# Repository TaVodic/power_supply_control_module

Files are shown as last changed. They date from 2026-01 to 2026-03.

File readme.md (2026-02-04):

# Laboratory Power Supply Control Module (PSCM)   

Module is an upgarde for Nice-Power SPS305 0-30V/0-5A laboratory power supply. Module use encoders instead of potentiometers. Based on ATmega328PB.
Using arduino-cli framework.  
### Features:
* Encoders EC12E, fine and coarse set of volatge and current
* Digital potentiometers MCP4251
* ATmega328PB
* Sniffing the PS voltage, current and power - providing a feedback
* UART connection for PC connection and automated PS setting

### Libraries used:
* Encoder_mt, [original](https://github.com/PaulStoffregen/Encoder) modified to use PCINT and optimized for the use-case
* DispSniff, sniffing SDI & CLK pins of TM1640 (of the original PS) to capture voltage, current and power values of the PS
* MCP4251, [original](https://github.com/kulbhushanchand/MCP4251)

## [Schematic v1.0.0](docu/pscm_schematic_v1.0.0.pdf)

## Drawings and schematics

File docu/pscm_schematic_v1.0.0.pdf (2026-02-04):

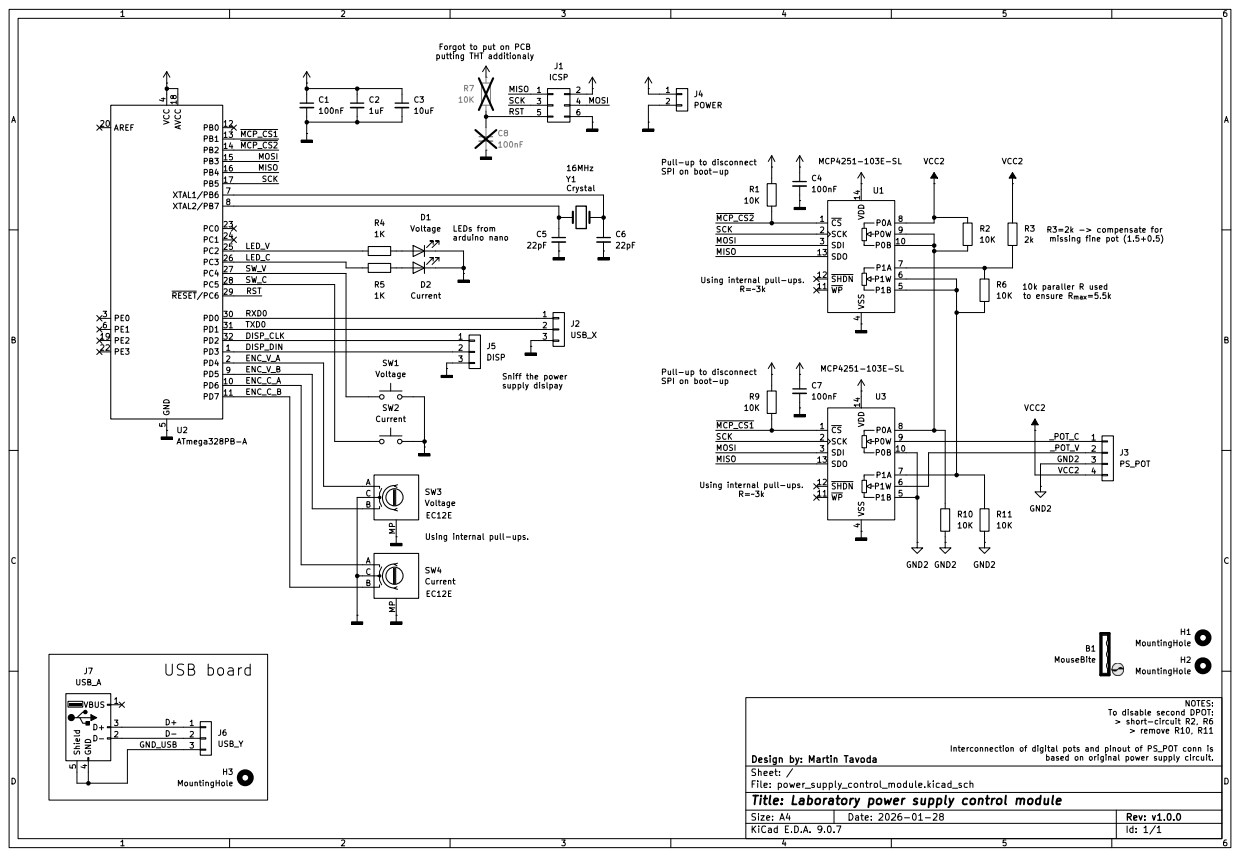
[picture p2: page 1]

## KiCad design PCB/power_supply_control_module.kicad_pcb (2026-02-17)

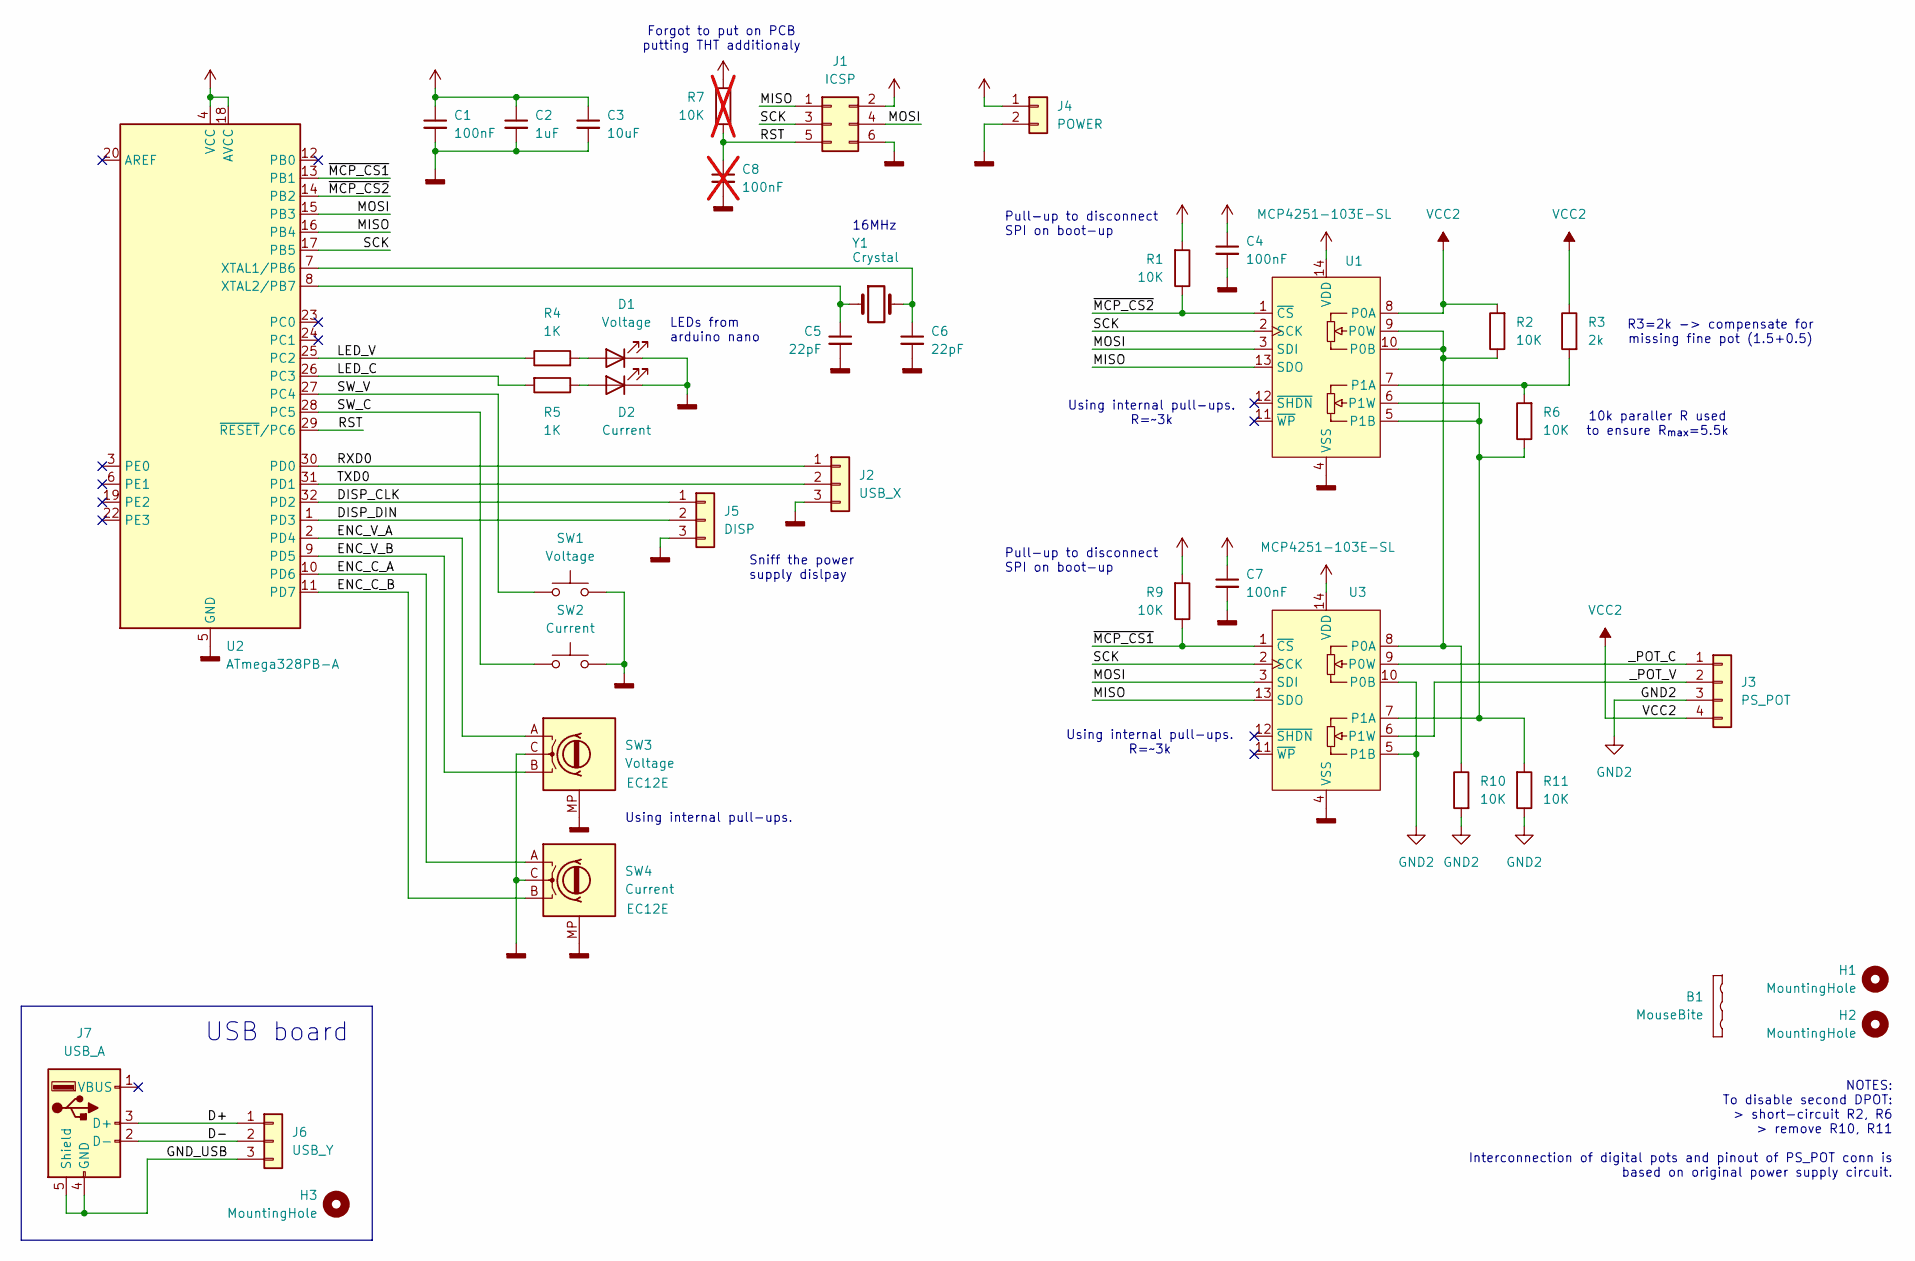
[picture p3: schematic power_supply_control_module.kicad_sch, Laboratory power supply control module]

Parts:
B1: MouseBite; mouse-bite-3mm-slot-jlcpcb
C1, C4, C7: 100nF; C_1206_3216Metric_Pad1.33x1.80mm_HandSolder
C2: 1uF; C_1206_3216Metric_Pad1.33x1.80mm_HandSolder
C3: 10uF; C_1206_3216Metric_Pad1.33x1.80mm_HandSolder
C5, C6: 22pF; C_1206_3216Metric_Pad1.33x1.80mm_HandSolder
C8: 100nF; C_1206_3216Metric_Pad1.33x1.80mm_HandSolder; not fitted
D1: Voltage; LED_0603_1608Metric_Pad1.05x0.95mm_HandSolder
D2: Current; LED_0603_1608Metric_Pad1.05x0.95mm_HandSolder
H1, H2, H3: MountingHole; MountingHole_3.2mm_M3_ISO7380
J1: ICSP; PinHeader_2x03_P2.54mm_Vertical
J2: USB_X; SHDR3W50P0X200_1X3_800X470X640P
J3: PS_POT; JST_XH_B4B-XH-A_1x04_P2.50mm_Vertical
J4: POWER; 140502415001
J5: DISP; SHDR3W50P0X200_1X3_800X470X640P
J6: USB_Y; PinHeader_1x03_P2.00mm_Vertical
J7: USB_A; USB_A_Molex_105057_Vertical
R1, R2, R6, R9, R10, R11: 10K; R_1206_3216Metric_Pad1.30x1.75mm_HandSolder
R3: 2k; R_1206_3216Metric_Pad1.30x1.75mm_HandSolder
R4, R5: 1K; R_1206_3216Metric_Pad1.30x1.75mm_HandSolder
R7: 10K; R_1206_3216Metric_Pad1.30x1.75mm_HandSolder; not fitted
SW1: Voltage; SW_TH_Tactile_Omron_B3F-107x
SW2: Current; SW_TH_Tactile_Omron_B3F-107x
SW3: Voltage; RotaryEncoder_Alps_EC12E_Vertical_H20mm
SW4: Current; RotaryEncoder_Alps_EC12E_Vertical_H20mm
U1, U3: MCP4251-103E-SL; SOIC-14_3.9x8.7mm_P1.27mm
U2: ATmega328PB-A; TQFP-32_7x7mm_P0.8mm
Y1: Crystal; Crystal_HC49-4H_Vertical

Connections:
/D+: J6.1, J7.3 (D+)
/D-: J6.2, J7.2 (D-)
/DISP_CLK: J5.1, U2.32 (PD2)
/DISP_DIN: J5.2, U2.1 (PD3)
/ENC_C_A: SW4.A, U2.10 (PD6)
/ENC_C_B: SW4.B, U2.11 (PD7)
/ENC_V_A: SW3.A, U2.2 (PD4)
/ENC_V_B: SW3.B, U2.9 (PD5)
/GND_USB: J6.3, J7.4 (GND), J7.5 (Shield)
/LED_C: R5.2, U2.26 (PC3)
/LED_V: R4.1, U2.25 (PC2)
/MISO: J1.1, U1.13 (SDO), U2.16 (PB4), U3.13 (SDO)
/MOSI: J1.4, U1.3 (SDI), U2.15 (PB3), U3.3 (SDI)
/RST: C8.1, J1.5, R7.1, U2.29 (~RESET/PC6)
/RXD0: J2.1, U2.30 (PD0)
/SCK: J1.3, U1.2 (SCK), U2.17 (PB5), U3.2 (SCK)
/SW_C: SW2.1, U2.28 (PC5)
/SW_V: SW1.1, U2.27 (PC4)
/TXD0: J2.2, U2.31 (PD1)
/_POT_C: J3.1, U3.9 (P0W)
/_POT_V: J3.2, U3.6 (P1W)
/~MCP_CS1: R9.1, U2.13 (PB1), U3.1 (~CS)
/~MCP_CS2: R1.1, U1.1 (~CS), U2.14 (PB2)
GND2: J3.3, R10.2, R11.1, U3.5 (P1B), U3.10 (P0B)
GNDD: C1.2, C2.2, C3.2, C4.2, C5.2, C6.2, C7.2, C8.2, D1.1 (K), D2.1 (K), J1.6, J2.3, J4.2, J5.3, SW1.2, SW2.2, SW3.C, SW3.MP, SW4.C, SW4.MP, U1.4 (VSS), U2.5 (GND), U2.21 (GND), U3.4 (VSS)
unnamed: D1.2 (A), R4.2
unnamed: D2.2 (A), R5.1
unnamed: R2.1, R10.1, U1.9 (P0W), U1.10 (P0B), U3.8 (P0A)
unnamed: R3.2, R6.2, U1.7 (P1A)
unnamed: R6.1, R11.2, U1.5 (P1B), U1.6 (P1W), U3.7 (P1A)
unnamed: C6.1, U2.7 (XTAL1/PB6), Y1.2
unnamed: C5.1, U2.8 (XTAL2/PB7), Y1.1
VCC: C1.1, C2.1, C3.1, C4.1, C7.1, J1.2, J4.1, R1.2, R7.2, R9.2, U1.14 (VDD), U2.4 (VCC), U2.18 (AVCC), U3.14 (VDD)
VCC2: J3.4, R2.2, R3.1, U1.8 (P0A)

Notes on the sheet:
Forgot to put on PCB putting THT additionaly
Using internal pull-ups. R=~3k
Pull-up to disconnect SPI on boot-up
10k paraller R used to ensure R_{max}=5.5k
NOTES: To disable second DPOT: > short-circuit R2, R6 > remove R10, R11 Interconnection of digital pots and pinout of PS_POT conn is based on original power supply circuit.
Using internal pull-ups.
R3=2k -> compensate for missing fine pot (1.5+0.5)
16MHz
USB board
Sniff the power supply dislpay
LEDs from arduino nano

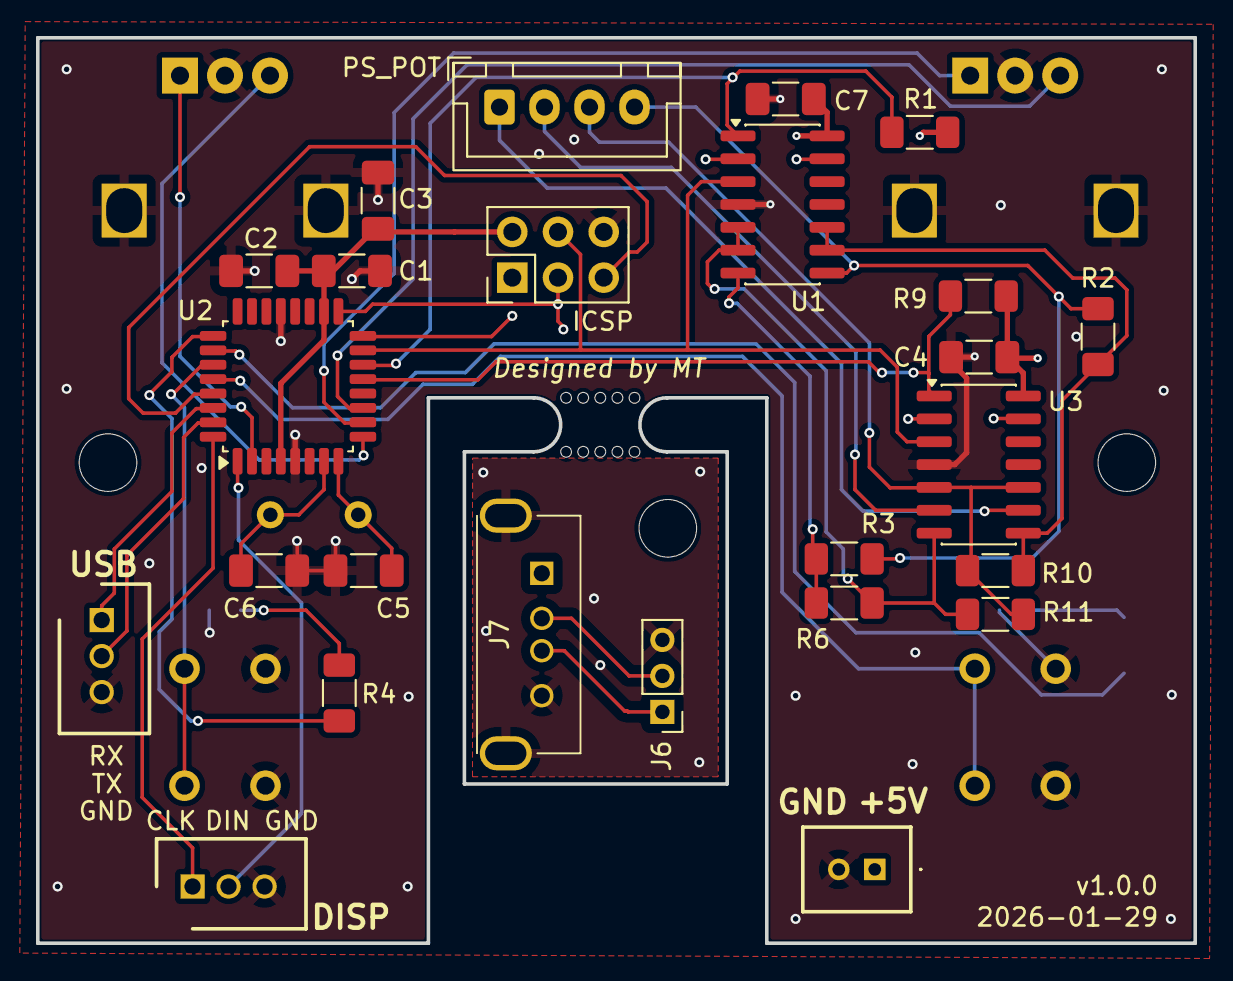
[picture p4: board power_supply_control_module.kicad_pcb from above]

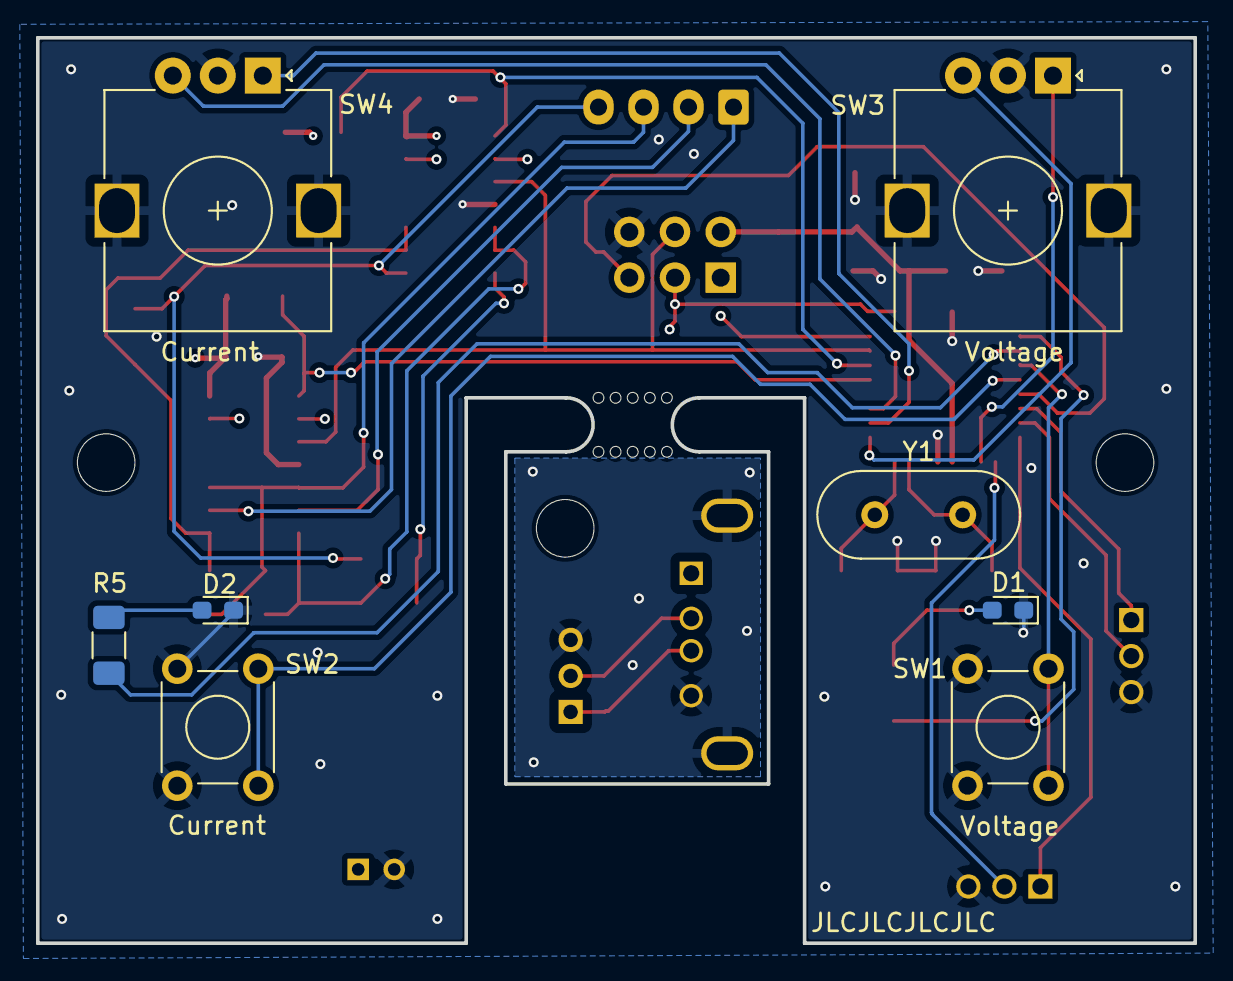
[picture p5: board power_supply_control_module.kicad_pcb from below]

Board: 4 copper layers, 64.3 x 50.3 mm, 37 parts (8 on the bottom side), 34 nets.

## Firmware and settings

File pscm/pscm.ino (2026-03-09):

#include "Encoder_mt.h"
#include "MCP4251.h"
#include "dispsniff.h"
#include "pscm.h"

#include <Arduino.h>
#include <stdint.h>
#include <util/atomic.h>

#define MAIN_DEBUG

MCP4251 MCP_1(pin_MCP_CS1);
MCP4251 MCP_2(pin_MCP_CS2);
Encoder ENC_V;
Encoder ENC_C;

uint16_t meas_voltage = 0;
uint16_t meas_current = 0;
uint16_t meas_power = 0;

enum mode_t : uint8_t {
  FINE,
  COARSE
};

enum MCP_adddr : uint8_t {
  CURRENT = 0,
  VOLTAGE = 1,
};

struct el_quantity_t {
  Encoder *ENC;
  MCP_adddr mcp_addr;
  int16_t old_enc_position = 0;
  volatile uint8_t btn_oldState = 1;
  volatile uint32_t btn_lastMillis = 0;
  volatile mode_t mode = COARSE;
  uint16_t wiper = 0;
};

el_quantity_t Voltage = {&ENC_V, VOLTAGE};
el_quantity_t Current = {&ENC_C, CURRENT};

void io_init() {
  pinMode(pin_LED_V, OUTPUT);
  pinMode(pin_LED_C, OUTPUT);
  pinMode(pin_SW_V, INPUT_PULLUP);
  pinMode(pin_SW_C, INPUT_PULLUP);

  // debug pins
  pinMode(8, OUTPUT);  // debug pin PB0
  pinMode(A0, OUTPUT); // debug pin PC0

  *digitalPinToPCMSK(pin_SW_V) |= (1 << digitalPinToPCMSKbit(pin_SW_V)); // PCINT12 Pin Change Mask Register //PC4
  *digitalPinToPCMSK(pin_SW_C) |= (1 << digitalPinToPCMSKbit(pin_SW_C)); // PCINT13 Pin Change Mask Register //PC5
  PCICR |= (1 << digitalPinToPCICRbit(pin_SW_V));                        // Pin Change Interrupt Control Register (PCIE1)
  PCICR |= (1 << digitalPinToPCICRbit(pin_SW_C));                        // Pin Change Interrupt Control Register (PCIE1)
}

void setup() {
  MCP_1.begin();
  MCP_2.begin();
  MCP_1.DigitalPotSetWiperMin(0);
  MCP_1.DigitalPotSetWiperMin(1);
  MCP_2.DigitalPotSetWiperMin(0); // short-circuit DPOT2
  MCP_2.DigitalPotSetWiperMin(1); // short-circuit DPOT2

  io_init();

  Serial.begin(115200);
  Serial.println();
  Serial.println("TM1640 sniff start ");

  if (!Voltage.ENC->begin(pin_ENC_V_B, pin_ENC_V_A)) {
    Serial.println("ENC_V init failed: only PD4,PD5,PD6,PD7 are supported!");
  }
  if (!Current.ENC->begin(pin_ENC_C_B, pin_ENC_C_A)) {
    Serial.println("ENC_C init failed: only PD4,PD5,PD6,PD7 are supported!");
  }
  dispsniff_begin();

  for (uint8_t i = 0; i < 3; i++) {
    digitalWrite(pin_LED_V, HIGH);
    digitalWrite(pin_LED_C, HIGH);
    delay(100);
    digitalWrite(pin_LED_V, LOW);
    digitalWrite(pin_LED_C, LOW);
    delay(100);
  }

  MCP_1.DigitalPotSetWiperMin(0);
  MCP_1.DigitalPotSetWiperMin(1);
  MCP_2.DigitalPotSetWiperMin(0);
  MCP_2.DigitalPotSetWiperMin(1);

  int16_t wiper = MCP_1.DigitalPotReadWiperPosition(Voltage.mcp_addr);
#ifdef MAIN_DEBUG
  Serial.print("init wiper: ");
  Serial.println(wiper);
#endif
}

void loop() {
  dispsniff_poll(&meas_voltage, &meas_current, &meas_power);
  static uint32_t cmillis = 0;
  if (millis() > 100 + cmillis) {    
    Serial.print("M");
    Serial.write(meas_voltage);
    Serial.write(meas_current);
    Serial.write(meas_power);
    Serial.write(Voltage.wiper);
    Serial.write(Current.wiper);
    Serial.print("\r\n");
    cmillis = millis();
  }

  set_el_quantity(&Voltage);
  set_el_quantity(&Current);

  if (Voltage.mode == FINE) {
    digitalWrite(pin_LED_V, HIGH);
  } else {
    digitalWrite(pin_LED_V, LOW);
  }
  if (Current.mode == FINE) {
    digitalWrite(pin_LED_C, HIGH);
  } else {
    digitalWrite(pin_LED_C, LOW);
  }
}

void set_el_quantity(el_quantity_t *quantity) {
  int16_t newPosition = (int16_t)quantity->ENC->read();
  int16_t diff = newPosition - quantity->old_enc_position;
  int16_t tempWiper;
  int16_t wiper_1 = MCP_1.DigitalPotReadWiperPosition(quantity->mcp_addr);
  int16_t wiper_2 = MCP_2.DigitalPotReadWiperPosition(quantity->mcp_addr);
  int16_t wiper = wiper_1 + wiper_2;

  if (diff != 0) {
#ifdef MAIN_DEBUG
    Serial.print("read wiper_1: ");
    Serial.println(wiper_1);
    Serial.print("read wiper_2: ");
    Serial.println(wiper_2);
    Serial.print("read wiper_sum: ");
    Serial.println(wiper);
#endif
    if (quantity->mode == COARSE) {
      diff *= COARSE_RES;
    }
    ATOMIC_BLOCK(ATOMIC_RESTORESTATE) {
      tempWiper = wiper + diff; // TODO: wiper get stuc when we chnage mode
    }
    ATOMIC_BLOCK(ATOMIC_RESTORESTATE) {
      if (tempWiper < 0) {
        wiper = 0;
      } else if (tempWiper > WIPERS_MAX_VAL) {
        wiper = WIPERS_MAX_VAL;
      } else {
        wiper = tempWiper;
      }
    }
#ifdef MAIN_DEBUG
    Serial.print("wiper: ");
    Serial.println(wiper);
#endif
    quantity->old_enc_position = newPosition;
    quantity->wiper = wiper;
    if (wiper > WIPER_MAX_VAL) {
      MCP_1.DigitalPotSetWiperMax(quantity->mcp_addr);
      MCP_2.DigitalPotSetWiperPosition(quantity->mcp_addr, wiper - 256);
    } else {
      MCP_1.DigitalPotSetWiperPosition(quantity->mcp_addr, wiper);
      MCP_2.DigitalPotSetWiperMin(quantity->mcp_addr);
    }
  }
}

void UART_handler(void) {
  while (Serial.available() > 0) {
    static char receivedMessage[SER_BUFF_SIZE];
    static char *p_receivedMessage;
    if (p_receivedMessage == NULL) p_receivedMessage = receivedMessage;

    char receivedChar = Serial.read();
    // Serial.print(receivedChar);
    if (receivedChar == '\n') {
      // Serial.println(receivedMessage);  // Print the received message in the Serial monitor
      *(++p_receivedMessage) = '\0';
      // Serial.printf("Received msg: %s\r\n", receivedMessage);

      const char commandPrefix[] = "cmd:";
      char *p_index = strstr(receivedMessage, commandPrefix);
      if (p_index != NULL) {
        p_index = (p_index + sizeof(commandPrefix) - 1);
        // Serial.printf("Command: %s\n", p_index);
        // TODO: Parse the msg
      }

      memset(receivedMessage, 0, sizeof(receivedMessage));  // TODO: teoreticly can be ommited
      p_receivedMessage = NULL;
    } else {
      *p_receivedMessage = receivedChar;  // Append characters to the received message
      p_receivedMessage++;
      if ((p_receivedMessage - &receivedMessage[0]) > sizeof(receivedMessage)) {
        Serial.printf("ERROR: Recieved message larger than expected!\r\n");
        while (Serial.available() > 0) Serial.read();
        memset(receivedMessage, 0, sizeof(receivedMessage));  // TODO: teoreticly can be ommited
        p_receivedMessage = NULL;
        return;
      }
    }
  }
}

ISR(PCINT1_vect) { // max 10us
#ifdef MAIN_DEBUG
  PORTC |= (1u << PC0);
#endif

  if (!READ_DPIN(pin_SW_V) && Voltage.btn_oldState) {
    if (millis() > BTN_DEBOUNCE_MS + Voltage.btn_lastMillis) {
      Voltage.mode = (Voltage.mode == COARSE) ? FINE : COARSE;
      Voltage.btn_oldState = 0;
      Voltage.btn_lastMillis = millis();
    }
  } else if (READ_DPIN(pin_SW_V) && !Voltage.btn_oldState) {
    Voltage.btn_oldState = 1;
    Voltage.btn_lastMillis = millis();
  }

  if (!READ_DPIN(pin_SW_C) && Current.btn_oldState) {
    if (millis() > BTN_DEBOUNCE_MS + Current.btn_lastMillis) {
      Current.mode = (Current.mode == COARSE) ? FINE : COARSE;
#ifdef MAIN_DEBUG
      PORTB ^= (1u << PB0);
#endif
      Current.btn_oldState = 0;
      Current.btn_lastMillis = millis();
    }
  } else if (READ_DPIN(pin_SW_C) && !Current.btn_oldState) {
    Current.btn_oldState = 1;
    Current.btn_lastMillis = millis();
  }
#ifdef MAIN_DEBUG
  PORTC &= ~(1u << PC0);
#endif
}

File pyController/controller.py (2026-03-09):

import threading
import tkinter as tk
from tkinter import ttk, messagebox

import serial
import serial.tools.list_ports


class PSUApp:
    def __init__(self, root):
        self.root = root
        self.root.title("Power Monitor")
        self.root.geometry("420x560")
        self.root.configure(bg="#111111")

        self.ser = None
        self.read_thread = None
        self.running = False

        self.v_var = tk.StringVar(value="30.00")
        self.c_var = tk.StringVar(value="5.000")
        self.p_var = tk.StringVar(value="5.000")
        self.input_voltage_var = tk.StringVar()
        self.input_current_var = tk.StringVar()
        self.wiper_voltage_var = tk.StringVar(value="--")
        self.wiper_current_var = tk.StringVar(value="--")
        self.port_var = tk.StringVar()

        self.build_ui()
        self.refresh_ports()
        self.auto_connect_cp2102()

        self.root.protocol("WM_DELETE_WINDOW", self.on_close)

    def build_ui(self):
        num_vcmd = (self.root.register(self.validate_numeric), "%P")

        self.top = tk.Frame(self.root, bg="#111111")
        self.top.pack(fill="x", padx=14, pady=(12, 8))

        self.port_box = ttk.Combobox(
            self.top,
            textvariable=self.port_var,
            state="readonly",
            width=18
        )
        self.port_box.pack(side="left", padx=(0, 8))

        refresh_btn = ttk.Button(self.top, text="Refresh", command=self.refresh_ports)
        refresh_btn.pack(side="left", padx=(0, 8))

        self.conn_btn = ttk.Button(self.top, text="Connect", command=self.toggle_connection)
        self.conn_btn.pack(side="left")

        self.shell = tk.Frame(self.root, bg="#1b1b1b", bd=2, relief="ridge")
        self.shell.pack(fill="both", expand=True, padx=14, pady=12)

        bezel = tk.Frame(self.root, bg="#2a2a2a")
        bezel.place(in_=self.shell, relx=0.5, rely=0.5, anchor="center", relwidth=0.94, relheight=0.88)

        self.canvas = tk.Canvas(
            bezel,
            bg="#0b0b0b",
            highlightthickness=0,
            bd=0
        )
        self.canvas.pack(fill="both", expand=True, padx=8, pady=8)
        self.canvas.bind("<Configure>", self.redraw_panel)

        bottom = tk.Frame(self.root, bg="#111111")
        bottom.pack(fill="x", padx=14, pady=(0, 14))

        input_row = tk.Frame(bottom, bg="#111111")
        input_row.pack(fill="x", pady=(6, 8))

        right_input = tk.Frame(input_row, bg="#111111")
        right_input.pack(side="left", expand=True, fill="x", padx=(10, 0))
        tk.Label(
            right_input,
            text="Current [A]",
            fg="#f0f0f0",
            bg="#111111",
            font=("Segoe UI", 12, "bold")
        ).pack(pady=(0, 8))
        self.current_entry = tk.Entry(
            right_input,
            textvariable=self.input_current_var,
            justify="center",
            font=("Segoe UI", 12, "bold"),
            validate="key",
            validatecommand=num_vcmd,
            bg="#2a2a2a",
            fg="#f0f0f0"   
        )
        self.current_entry.pack(ipady=8, fill="x", padx=8)
        self.current_entry.bind("<Return>", self.send_current_input)
        self.current_entry.bind("<KP_Enter>", self.send_current_input)
        
        left_input = tk.Frame(input_row, bg="#111111")
        left_input.pack(side="left", expand=True, fill="x", padx=(0, 10))
        tk.Label(
            left_input,
            text="Voltage [V]",
            fg="#f0f0f0",
            bg="#111111",
            font=("Segoe UI", 12, "bold")
        ).pack(pady=(0, 8))
        self.voltage_entry = tk.Entry(
            left_input,
            textvariable=self.input_voltage_var,
            justify="center",
            font=("Segoe UI", 12, "bold"),
            validate="key",
            validatecommand=num_vcmd,
            bg="#2a2a2a",
            fg="#f0f0f0"            
        )
        self.voltage_entry.pack(ipady=8, fill="x", padx=8)
        self.voltage_entry.bind("<Return>", self.send_voltage_input)
        self.voltage_entry.bind("<KP_Enter>", self.send_voltage_input)
        
        wiper_row = tk.Frame(bottom, bg="#111111")
        wiper_row.pack(fill="x", pady=(10, 0))
        wiper_right = tk.Frame(wiper_row, bg="#111111")
        wiper_right.pack(side="left", expand=True, fill="x", padx=(10, 0))
        wiper_left = tk.Frame(wiper_row, bg="#111111")
        wiper_left.pack(side="left", expand=True, fill="x", padx=(0, 10))
        tk.Label(
            wiper_right,
            textvariable=self.wiper_current_var,
            fg="#f0f0f0",
            bg="#111111",
            font=("Segoe UI", 12, "bold"),
            anchor="center"
        ).pack(fill="x")

        tk.Label(
            wiper_left,
            textvariable=self.wiper_voltage_var,
            fg="#f0f0f0",
            bg="#111111",
            font=("Segoe UI", 12, "bold"),
            anchor="center"
        ).pack(fill="x")


        

    def refresh_ports(self):
        ports = [p.device for p in serial.tools.list_ports.comports()]
        self.port_box["values"] = ports
        if ports:
            if self.port_var.get() not in ports:
                self.port_var.set(ports[0])
        else:
            self.port_var.set("")

    def find_cp2102_port(self):
        for port_info in serial.tools.list_ports.comports():
            if getattr(port_info, "vid", None) == 0x10C4 and getattr(port_info, "pid", None) == 0xEA60:
                return port_info.device

            searchable = " ".join(
                str(getattr(port_info, attr, "") or "")
                for attr in ("description", "manufacturer", "product", "hwid")
            ).lower()
            if "cp2102" in searchable:
                return port_info.device
        return None

    def auto_connect_cp2102(self):
        if self.running:
            return

        cp2102_port = self.find_cp2102_port()
        if cp2102_port:
            self.port_var.set(cp2102_port)
            self.connect()

    def toggle_connection(self):
        if self.running:
            self.disconnect()
        else:
            self.connect()

    def connect(self):
        port = self.port_var.get().strip()
        if not port:
            messagebox.showwarning("No port", "Please select a COM port.")
            return

        try:
            self.ser = serial.Serial(port, baudrate=115200, timeout=0.2)
            self.running = True
            self.conn_btn.config(text="Disconnect")
            self.top.pack_forget()
            self.read_thread = threading.Thread(target=self.read_loop, daemon=True)
            self.read_thread.start()
        except Exception as e:
            messagebox.showerror("Connection error", str(e))
            self.ser = None
            self.running = False
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

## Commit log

2026-01-25 PCB project created
    [power_supply_control_module.kicad_pcb, power_supply_control_module.kicad_sch]
2026-01-25 schematic and board WIP
    [power_supply_control_module.kicad_pcb, power_supply_control_module.kicad_sch]
2026-01-26 second MCP added WIP
    [power_supply_control_module.kicad_pcb, power_supply_control_module.kicad_sch]
2026-01-26 Schematic finished
    [power_supply_control_module.kicad_pcb, power_supply_control_module.kicad_sch]
2026-01-26 PCB WIP
    [power_supply_control_module.kicad_pcb]
2026-01-27 added USB PCB, before connecting the PCBs
    [power_supply_control_module.kicad_pcb, power_supply_control_module.kicad_sch]
2026-01-27 USB PCB finished
    [power_supply_control_module.kicad_pcb, power_supply_control_module.kicad_sch]
2026-01-28 routing finished
    [power_supply_control_module.kicad_pcb, power_supply_control_module.kicad_sch]
2026-01-28 PCB finished, JLCPCB ordered
    [power_supply_control_module.kicad_pcb, power_supply_control_module.kicad_sch]
2026-01-28 added forgotten RST pin treatement
    [power_supply_control_module.kicad_sch]
2026-01-30 [SW] keep only last frame WIP
2026-02-01 [SW] Encoder implementation, using INT0 & INT1
2026-02-02 [SW] one encoder working nice
2026-02-02 [SW] encoder working fine but uses INT and polling - not a good practise
2026-02-02 [SW] One encoder working perfectly
    - no polling, just PCINT
    - TIMER1 to debounce the pins, 600us gate
2026-02-02 [SW] Encoder pins treatement (only PD4-7)
2026-02-02 [SW] Optimization - interruptArgs[28] removed, only two ENC supported
2026-02-02 [SW] Two encoders perfectly working
2026-02-03 [SW] debounced buttons added
    [power_supply_control_module.kicad_sch]
2026-02-17 buttons fixed
    [power_supply_control_module.kicad_pcb]
2026-02-17 encoder quandrature reading changed to single count when specific transition happen
2026-02-18 successfully setting voltage and current
    [power_supply_control_module.kicad_sch]
2026-03-08 fuses and decrement issues repaired
    [pscm.ino]
2026-03-08 bootloader burned, UART programming not working
    [pscm.h, pscm.ino]
